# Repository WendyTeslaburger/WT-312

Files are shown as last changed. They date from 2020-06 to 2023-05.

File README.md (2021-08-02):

# WT-312, a MK-312 style driver on a stick!
## About:
This project aims to bring the hardware of e-stim/TENS to an easy-to-use module. Think: Sparkfun, Adafruit, DFRobot, etc.
I build this project with the main goal of interfacing to an ESP32 processor so many of the documentation or some design decissions will be made towards this processor. But you should be able to use your own favorite MCU.

This device tries to mimic the output stage of the well-known Erostec ET312 or better, the DIY reverse engineered MK-312. Hopefully by recreating this output stage, the same e-stim experience can be achieved as those devices.

## Current project status:
- ✅ Create V1.0 schematic+PCB
- ✅ V1.0 Testing and debugging 
- ✅ Commit V1.1 BOM patches
- ✅ Create V2.0 Schematic
- ✅ Route V2.0 PCB
- 🟧 Review process (ongoing)
- 🔲 Fix BOM with (available) alternative sources 
- 🔲 Order new batch of V2.0 PCBs

## Theory of operation:
### Output stage:
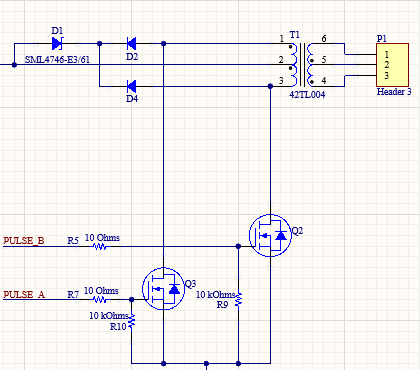
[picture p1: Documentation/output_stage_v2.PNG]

Just like the ET/MT312 this stick uses a 42TL004 audio transformer with the primary connected to the TENS output and the secondary connected to some circuitry to generate pulses.

These pulses are generated by the microcontroller, it can controll frequency (how many pulses per second) and the duration of each pulse.

A single "pulse"  consists of two steps:
1. Apply a voltage on A-signal. This will make one of both N-FETs conductive and current will start to flow through half the windings of the transformer.
2. Apply a voltage on the B-signal. This will make current flow through the other half of the transformer and reverse the polarity of the output TENS signal. Thus making this a bi-polar TENS driver.

To prevent the an excessive high drain-source voltage on the N-MOS drivers because of back-EMF generated by the transformer, two diodes will clamp this voltage to a zener diode on top of the centre-tap voltage.

### Level control:
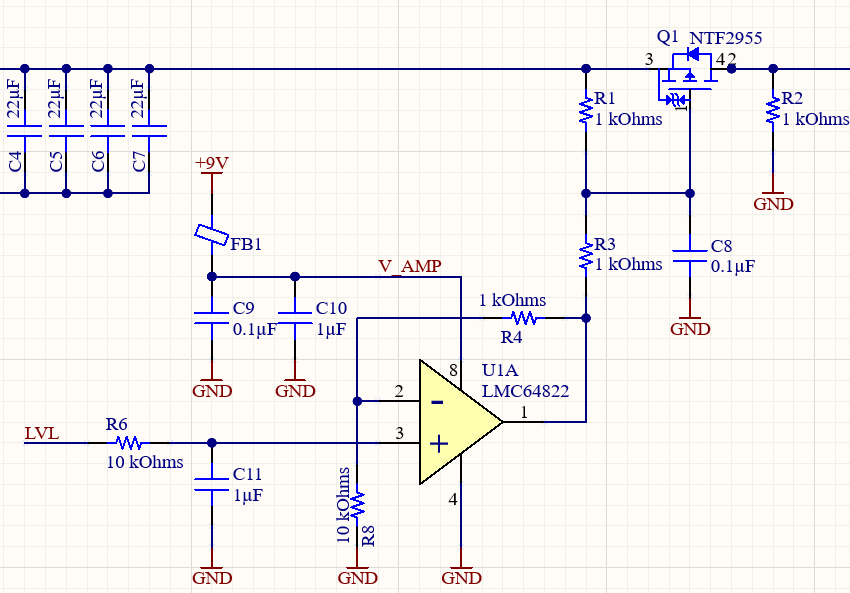
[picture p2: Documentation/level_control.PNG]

The intensity of a TENS stimulus is not only defined by the duration and frequency of the pulses, but also by the ouput power of that pulse. To control the output power of a pulse, we can limit how much current is flowing into the primary side of the transfomer.

By controlling the gate-voltage of a P-FET it is possible to control how much current that P-FET will allow to flow. An opamp is used to boost the I/o-voltage of the microcontroller to the 9V needed on the P-FET gate.

Important is to note that the LVL signal is inverted, a 0V means the P-FET is allowing maximal current and a 3.3V/5V will mean the P-FET is turned off.

### Current feedback:
Because not all P-FET are created 100% equally, it is important to first characterize the transfer curve between the LVL-signal and the current flowing through the transformer. This curve can be measured by the MCU on a embedded or external 
ADC on the *I_FB* pin of the WT-312 module.

To keep the voltage lost over the shunt resistor to a minimum, a small value shunt resistor is used and then amplified to the full-range of the ADC by an opamp.

## What is new in V2.0:
### 1. PWM
The DAC inside the ESP32 or ESP8266 is not great. Also, not every MCU has a built-in DAC to let alone 2, 3 or 4 DAC channels. However MCU's can generate pretty good resolution PWM signals and since the LVL signal does not require high bandwith, the V2.0 module has a R-C filter on the LVL signal so a PWM signal can be used instead of an analog DAC.
### 2. Improved clamping circuit
The clamping diodes in V1.0 ate into the power of the output. So they were removed in the patch. In V2.0 the clamping circuit is revised to let the voltage rise to a couple volts *above* the 9V input voltage. This should keep protecting the N-MOS but not impair the ouput power.
### 3. Bulk capacitance
Generating high-power pulses takes ... well ... power. These small 9V battery blocks have quite some internal resistance and are not able to generate the currents required for high-power TENS play. Not only batteries are bad a delivering pulses of several amps, also these ubiquitous chinese DCDC boost converter modules fail to deliver.

2 large electrolytic caps + a bunch of high value MLCC's will make sure that high current pulses to the primary can be delivered. The elco's can be mount sideways on the module to save some height.
### 4. LEDs
In this new design the REF pin is not used anymore. To keep compatibility between the V1.0 and V2.0 footprint the same number of pins was kept. This pin is now connected to a LED on the board. This LED is 100% optional and does not have to be stuffed, the footprint can be left empty.

## NodeMCU32s example (V1.0):
This is an example on how to connect the WT-312 module to the ESP32. This configuration will work with the provided example firmware.
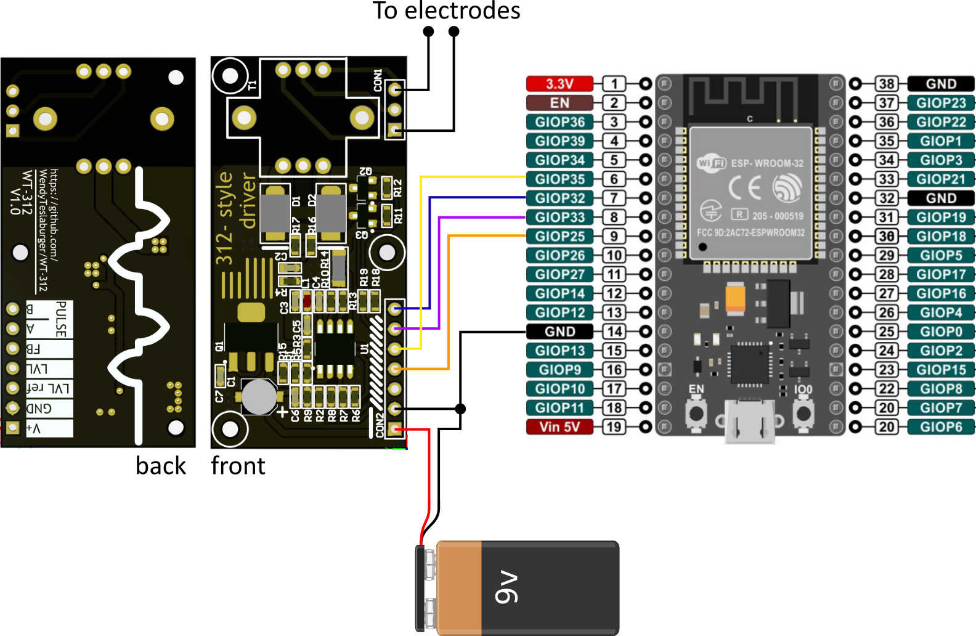
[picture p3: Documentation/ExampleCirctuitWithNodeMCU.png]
Connection example


## Licence:
All hardware design, software, images and documentation are licenced under the Creative Commons licence.

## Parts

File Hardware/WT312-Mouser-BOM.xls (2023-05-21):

SHOPPING BASKET
This is not an invoice
23-Apr-23 08:17:36
 | Mouser No | Mfr. No | Manufacturer | Customer No | Description | RoHS | Lifecycle | Order Qty. | Price (EUR)
1 | 80-C0603C104M5RAUTO | C0603C104M5RACAUTO | KEMET |  | Multilayer Ceramic Capacitors MLCC - SMD/SMT 50V 0.1uF X7R 0603 20% AEC-Q200 | RoHS Compliant |  | 3 | € 0,037
2 | 80-C0603C105K3R | C0603C105K3RACTU | KEMET |  | Multilayer Ceramic Capacitors MLCC - SMD/SMT 25V 1uF X7R 0603 10% | RoHS Compliant |  | 2 | € 0,179
3 | 81-GRM32ER71E226ME5L | GRM32ER71E226ME15L | Murata |  | Multilayer Ceramic Capacitors MLCC - SMD/SMT 22UF 25V 20% 1210 | RoHS Compliant |  | 4 | € 0,415
4 | 710-860020374012 | 860020374012 | Wurth Elektronik |  | Aluminium Electrolytic Capacitors - Radial Leaded WCAP-ATG5 470uF 16V 20% Radial | RoHS Compliant |  | 2 | € 0,244
5 | 78-SML4746-E3 | SML4746-E3/61 | Vishay |  | Zener Diodes 18 Volt 1.0W 10% | RoHS Compliant By Exemption |  | 1 | € 0,37
6 | 512-SS14FP | SS14FP | onsemi |  | Schottky Diodes & Rectifiers 40V 1A Schottky B arrier Rectifier | RoHS Compliant By Exemption |  | 2 | € 0,346
7 | 710-156120VS75000 | 156120VS75000 | Wurth Elektronik |  | Standard LEDs - SMD WL-SMRW SMD RvMt Mon Wtrclr Rect 1206BtGn | RoHS Compliant |  | 2 | € 0,184
8 | 704-MFBM1V1608-101-R | MFBM1V1608-101-R | Eaton |  | Ferrite Beads Multi H Cur, Impedance 100Ohm 2.5A SMT | RoHS Compliant |  | 1 | € 0,022
9 | 241-PJW4P06A_R200001 | PJW4P06A_R2_00001 | Panjit |  | MOSFET 60V P-Channel Enhancement Mode MOSFET | RoHS Compliant | New Product | 1 | € 0,348
10 | 621-DMN2041L-7 | DMN2041L-7 | Diodes Incorporated |  | MOSFET MOSFET,N-CHANNEL | RoHS Compliant |  | 2 | € 0,285
11 | 603-RC0603FR-101KL | RC0603FR-101KL | YAGEO |  | Thick Film Resistors - SMD 1 kOhms 100-200mW 06 03 1% | RoHS Compliant By Exemption |  | 4 | € 0,016
12 | 603-RT0603FRE1010RL | RT0603FRE1010RL | YAGEO |  | Thin Film Resistors - SMD 10 ohm 1% 50 ppm Thin Film | RoHS Compliant By Exemption |  | 2 | € 0,058
13 | 603-RC0603DR-0710KL | RC0603DR-0710KL | YAGEO |  | Thick Film Resistors - SMD 10 kOhms 100 mW 0603 1% | RoHS Compliant By Exemption |  | 5 | € 0,06
14 | 603-AC0603FR-10100KL | AC0603FR-10100KL | YAGEO |  | Thick Film Resistors - SMD 100 kOhms 100mW 0603 1% AEC-Q200 | RoHS Compliant By Exemption |  | 1 | € 0,028
15 | 603-RC0603FR-07560RP | RC0603FR-07560RP | YAGEO |  | Thick Film Resistors - SMD 560Ohms 1/10W 0603 1% | RoHS Compliant By Exemption |  | 2 | € 0,039
16 | 603-PE1206FRM7W0R1L | PE1206FRM7W0R1L | YAGEO |  | Current Sense Resistors - SMD 100 mOhms 1 Watt 1 % 75 ppm/C AEC-Q200 | RoHS Compliant |  | 1 | € 0,229
17 | 42TL004-RC | 42TL004-RC | Xicon |  | Audio Transformers / Signal Transformers XFMR 200CT-8 |  |  | 1 | € 3,78
18 | 926-LMC6482IM | LMC6482IM | Texas Instruments |  | Operational Amplifiers - Op Amps CMOS Dual RRIO OP Amp | No | NRND | 1 | € 2,44
19 | 523-G800W305018EU | G800W305018EU | Amphenol |  | Headers & Wire Housings Board mount - Header Plug - Pin Header 2.54mm Pitch Vertical,1x3Pin,Gold Flash,NY6T,6.1mm*2.5mm*3.0mm | RoHS Compliant |  | 1 | € 0,039
20 | 855-M20-9990746 | M20-9990746 | Harwin |  | Headers & Wire Housings 07 SIL VERTICAL PIN HEADER TIN | RoHS Compliant |  | 1 | € 0,234

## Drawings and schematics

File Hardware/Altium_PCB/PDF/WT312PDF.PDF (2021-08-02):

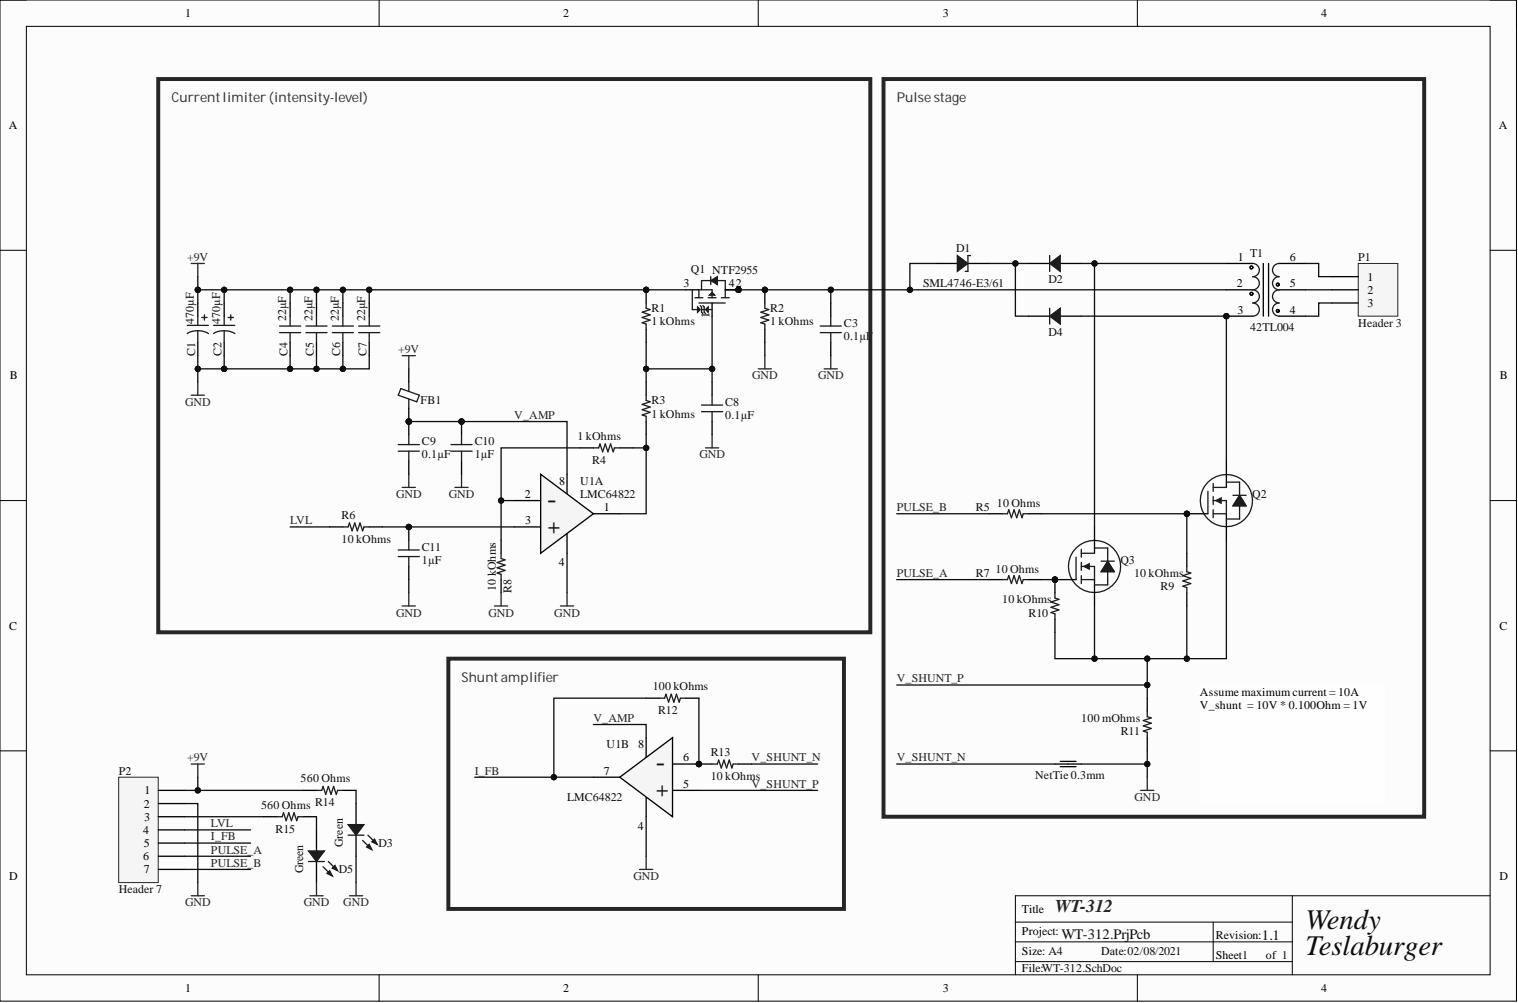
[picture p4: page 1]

Projec t : WT-3 1 2.P rj Pc b | Rev i s i o n : 1 . 1
Size : A 4 Dat e : 0 2 / 0 8 / 2 0 2 1 | Shee t 1 o f 1

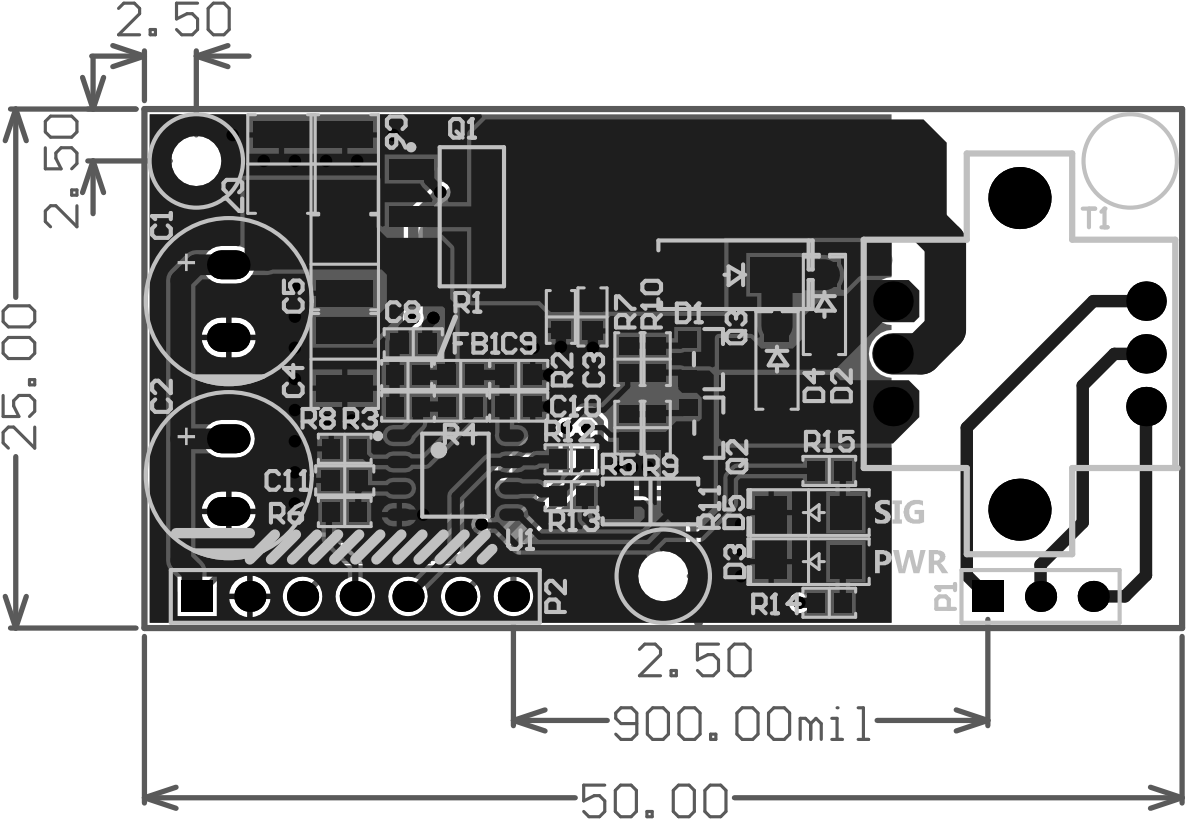
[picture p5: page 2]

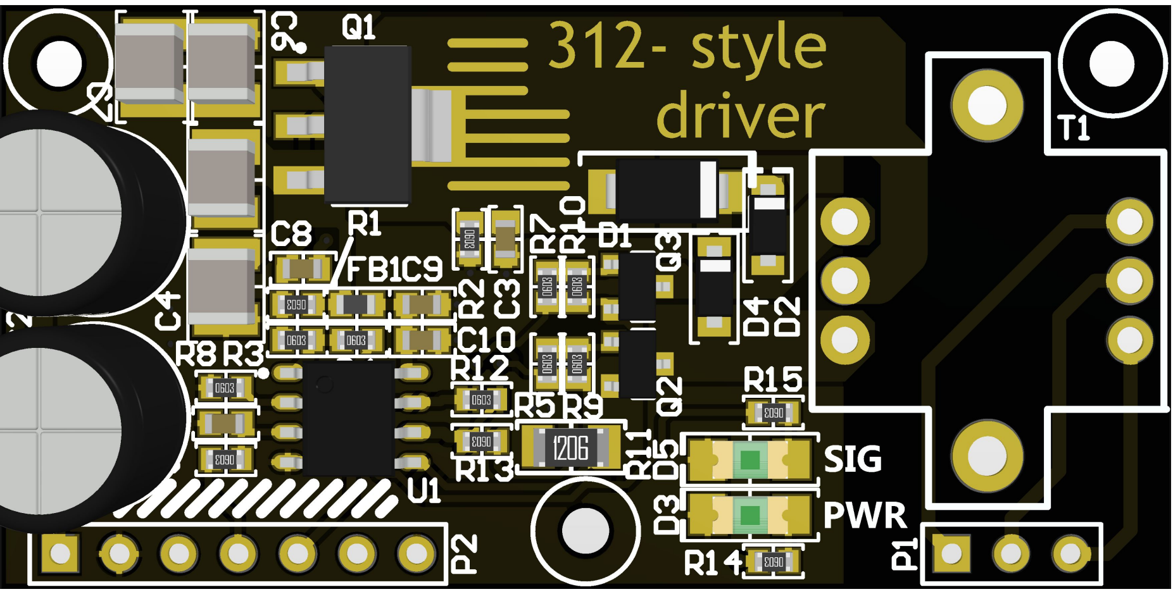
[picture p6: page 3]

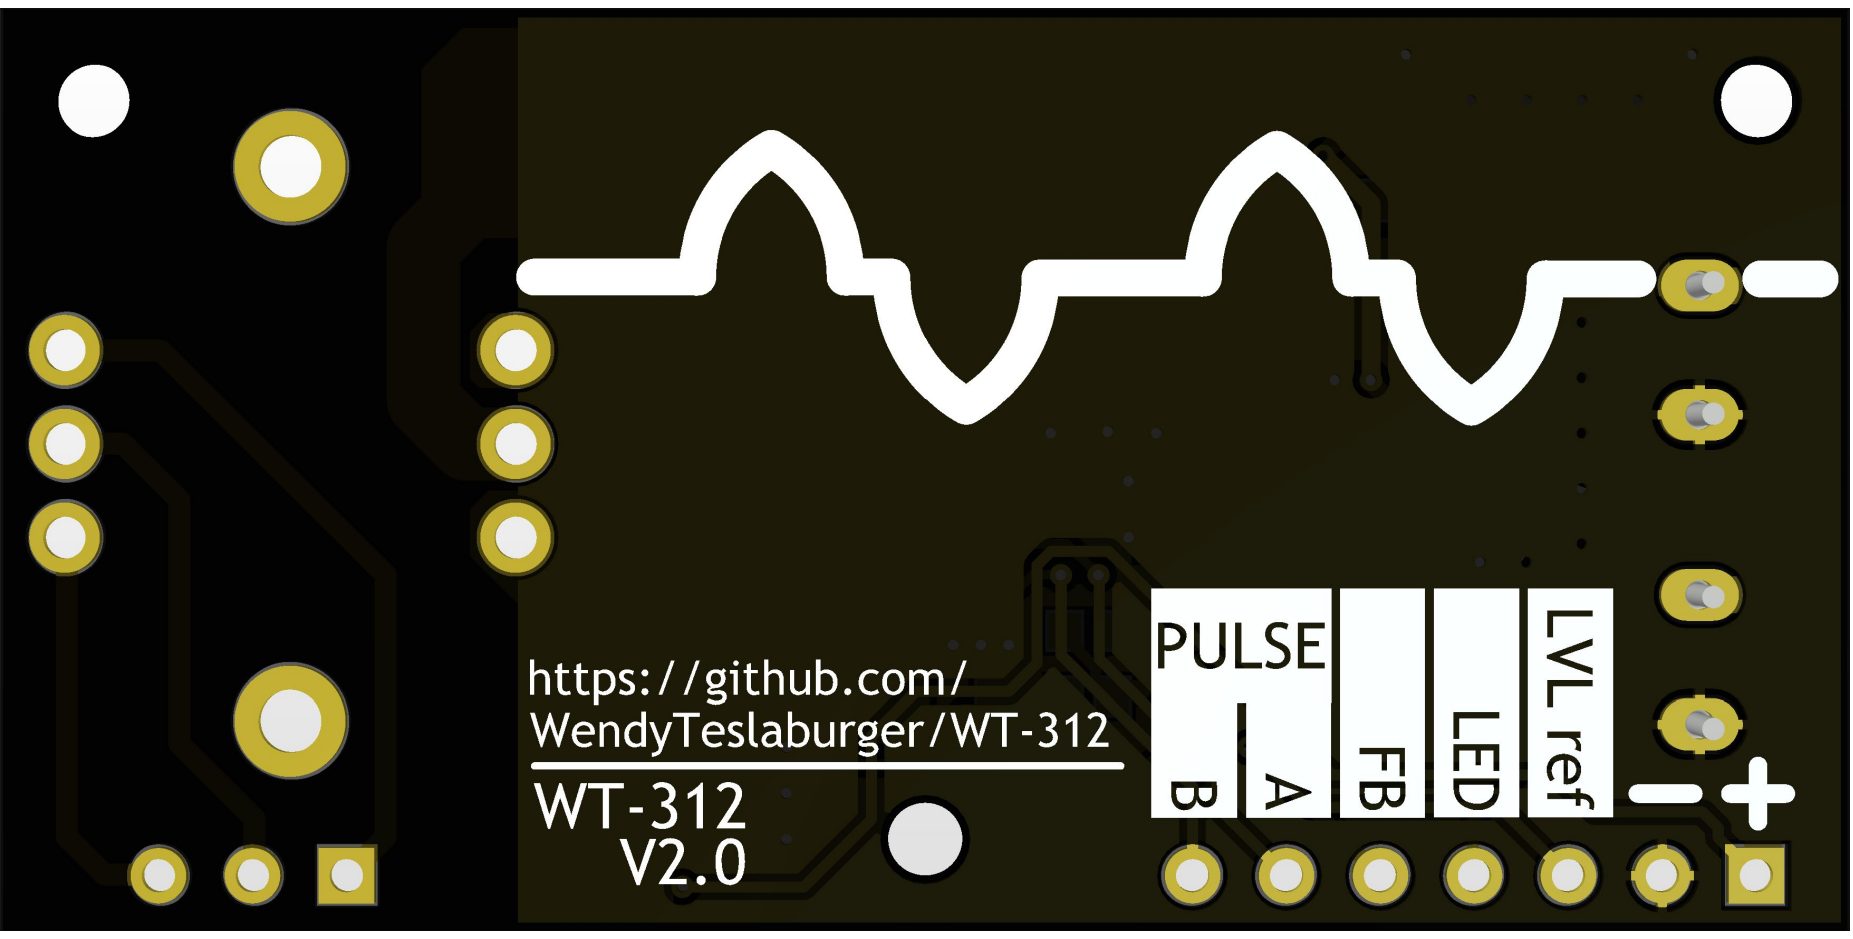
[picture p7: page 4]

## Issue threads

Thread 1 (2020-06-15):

T1 footprint optimisation

WendyTeslaburger, 2020-06-15:
The plated holes for the 42TL004 transformer are a bit on the tight side. Some force is required to push the mounting pins for the transformer, ruining the plating.
For extra mechanical support it would be good to also add exposed copper on top. So it is possible to solder the folded sheet metal to the PCB.
The issue does not affect performance, it only affects assembly.
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

Closed 2021-05-16.

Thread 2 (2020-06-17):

Feature request: Add PWM support

WendyTeslaburger, 2020-06-17:
Add support for low-pass filter on LVL, so the intensity can be set with PWM eliminating the need for a DAC.

WendyTeslaburger, 2021-07-19:
Implemented in the schematic: 2eabda08ca62eb708f5d9e8560ee80179203a66d

Closed 2021-07-19.

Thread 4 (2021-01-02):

Add bulk capacitance

WendyTeslaburger, 2021-01-02:
The bulk capacitance of 10uF is a few decades to low!
Something in the range of 1000uF - 2000uF should be sufficient.
When using alu-polymer caps, use a few in series to spread the ESR to a lower value.

WendyTeslaburger, 2021-07-19:
Implemented in schematic: 2eabda08ca62eb708f5d9e8560ee80179203a66d

Closed 2021-07-19.

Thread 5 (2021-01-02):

Current sense resistor on high side

WendyTeslaburger, 2021-01-02:
For increased output performance the, the shunt resistor can be decreased from 500mOhm to 100mOhm or even smaller.

WendyTeslaburger, 2021-07-19:
Implemented in schematic: 2eabda08ca62eb708f5d9e8560ee80179203a66d

Closed 2021-07-19.

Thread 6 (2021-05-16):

Schematic mismatch

maju101, 2021-05-16:
I seems that the pdf schematic and the PCB do not match. The schematic show 2 opamps (U1A and U1B), however the PCB only has room for 1.

I would greatly appreciate it if you could update the pdf schematic (and perhaps include a partslist). If you could do this update I will try to build it and add a partslist via Pull Request if I get it to work.

Thanks

WendyTeslaburger, 2021-05-16:
Hello, Thank you for your interest in my project!

U1A and U1B are both the same opamp. The LMC6482 is a dual opamp ([datasheet](https://www.ti.com/lit/ds/symlink/lmc6482.pdf?ts=1621152332898))
Splitting a component into multiple schematic subparts is a very common design technique.

However, after experimenting a bit with this module there are some slight variations I changed some component values for better performance. I should update these values into a new schematic PDF.

Best regards,
WT

maju101, 2021-05-16:
Ah ok cool.
Can I ask a couple more questions?

- The L1 coil is marked as z60. I'm assuming that's an impedance? If so, how does this translate to a coil rating in Henry?
- What size SMD components are you using? (i.e. 1206, 0603 ...)

Thanks
Cj

(and as promised, once I have everything assembled I'll add the full partslist via pullrequest so others who might be interested in this project can just buy everything without bothering you ;) )

WendyTeslaburger, 2021-05-18:
L1 is actually a filter bead. I could change the refdes to something like "FB1" to avoid confusion.
Z60 means that it has a 60ohm impedance at 100MHz. The filter bead is used to filter out protentional noise to the opamp. The noise could for example originate from a DCDC circuit to generate the 9v.

It is good practice to have it there, but I think the risk is low that the circuit would behave erratic if you just put a 0 ohm resistor there, or short the terminal with a solder blob.

The component size for the SMD components is 0603. For me this is the smallest size that is still comfortable to hand-solder.

jijzult, 2021-09-24:
I'd love a complete/matching BOM/schema too :) I'm following with great interests. I'll be trying to then make one with a LPR6235 coilcraft, so get a an ultrasmall size..

WendyTeslaburger, 2021-09-24:
I will try to get a BOM .csv file on the repo this weekend. Sorry for all the delays, I wish I had more time to work on this project.
Meanwhile some other kind strangers are testing out the design for me.

Regarding the LPR6235: I have doubts if this will work.
The LPR6235 is a tiny inductor and does not have a lot of material. This means that it will saturate quite fast.
The LPR6235-253LMR for example already saturates at 1.3A of primary current. This will not be sufficient for stronger e-stim output pulses.

maju101, 2021-09-24:
I was going to provide the bom as promised once I built it so I am sure
it's correct. But Mouser has absolutely massive delays. Currently expecting
my parts at the start of January...

On Fri, 24 Sep 2021, 17:04 WendyTeslaburger, ***@***.***>
wrote:

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

Closed 2023-05-21.

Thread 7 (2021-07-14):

small batch production run

McSwitchy, 2021-07-14:
Hi WendyTeslaburger - I am super impressed w/ your project and have been hoping someone would put together a small production run of the PCBs.

1. has anyone produced a batch of assembled PCBs or is planning to?

2. if not, I guess I would like to give it a shot. I've gotten pcb fab + assembly quotes from 1) circuithub.com and 2) pcbway.com in the past. However:

circuithub requires CAD files and not just gerbers - would you be willing to add those to this repo?
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

PCBway can work from gerber files, but needs a **centroid** file for each component for their pick-n-place process. See their requirements here: https://www.pcbway.com/helpcenter/pcb_assembly_ordering/

**first of all, is it ok w/ you for me to do a production run of this project? I would probably make 10-20 depending on price breaks and sell them at cost to anyone interested - alternatively I could just make a couple for personal use.** please let me know what you would prefer - I want to respect your wishes.

That said, assuming you support a small production run... Would you be open to:

1. creating the centroid file for PCBWay, or
2. providing the original atium design files so I can use circuithub;
2. and helping me pick good parts for the BOM
3. and providing advice (if any) on the optimal pcb and assembly options offered by pcbway (i.e. extra-thick copper layer for antenna / power / emf shielding etc)? See pcbway fab options in screenshot below

if not, I guess I would recreate the design in kicad or eagle and try out circuithub.

THanks! Other people interested in getting a board, chime in please so I can estimate interest.

McS

---

### PCBWAY manufacturing parameters

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

WendyTeslaburger, 2021-07-15:
Hey,
Thanks for your interest in the project! I will try to answer all your questions.

I have made a small batch of 10 PCBs at JLCPCB for testing and debugging the design. I hand-soldered them myself.
But as far as I'm aware, there has been no other production run.

I'm no copyright lawyer, but I tried to keep these project as open as possible so I included the Creative Commons Zero v1.0 licence. This should allow anyone to do whatever they want with the design. So I am 100% down with you running some production on these modules.

I use Altium Designer for my design work.
For this project I did not yet include the source documents because I was not sure if any personal information was inside .SchDoc or .PcbDoc metadata. For the WT-108 project I did some research and felt comfortable enough to commit the source documents. I will make a commit with the Altium source documents so you can use them (Circuithub) or even contribute to the project if you have an Altium licence.

Regarding the actual design itself: I had the chance to experiment with these boards and found some smal-ish issues. If any serious production run would be done, it would be best to make some changes to the design before making the modules.
Some are simple like substituting some component values with different values. But others would benefit from a small PCB redesign.

If you like, I could make these changes over the weekend and make a commit. Then we can have a look together at manufacturing options.

Best regards,
WT

McSwitchy, 2021-07-15:
Hi,

Most excellent! When you get the time to make the minor tweaks and then commit the updated atium files etc to the repo, I'll dig in and start trying to source parts and setting up a BOM. I'll try to do some of the heavy lifting there and also by soliciting a set of RFQs from the fab places. Then we can refine the BOM, order quantity, etc.

I'm glad I reached out, I've been meaning too for a year now :)

rexorient, 2021-07-22:
I would be interested in buying some assembled boards.

WendyTeslaburger, 2021-07-23:
Hello,
Sorry for the delay.
I have already made the changes to the schematic and committed the schematic in PDF together with the source .SchDoc file.
Next up I will change the routing a bit on the module PCB and commit that together with the Gerbers.

Regarding the BOM: I think the schematic is now as good as it gets with all the open issues fixed.
I will export a BOM list from Altium still today, then we can have a look if all components are available or if they need to be swapped for a different supplier (the component marking is crazy right now!)

Best regards,
WT

Deor, 2021-07-28:
Hi All,
I've just found this project and its just what i was looking for!
As I had also just put in an order with JLCPCB for some MK-312BT boards i decided to add this to the order too.
I know its still WIP, but for another £1.44 i thought why not!
If nothing else it will be good SMT soldering practice :)

KnkstrKex, 2021-08-05:
I'm also interesting in buying some (e.g. 5) completed boards.

h2omatt, 2022-09-11:
Did anyone make a few of these I am interested in buying a few to test with

EmiliaThorsen, 2024-06-08:
Any possibility for centroid files to be generated and added to the repo for production at jlcpcb/pcbway? I do not have altium so i can't generate the files myself, attempting to import the save files into kicad seems to have gotten the placements correctly, but i do not fully trust that it did everything correctly.

Otherwise a full conversion of the project to kicad would be amazing, but that is a lot to ask for so no need to, its only the centroid files for the pick and place i need to have it produced.

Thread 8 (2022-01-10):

Is there any software other besides the example?

Misaka13514, 2022-01-10:
Hi WendyTeslaburger! I am very interested in WT-312 because of its small size, low cost, etc.

I have completed the V2.0 of the hardware production.
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

When I tested the ESP32 software example, I found that neither V1 nor V2 software seemed to work properly on my device. It always enters the errorloop. (Sorry I don’t know how to view debugging information. I will try my best if you teach me.)

btw, is there any software other besides the example? Can the wireless function of esp32 be used to control pulse?

86lotus, 2023-03-31:
Hi .. did you ever get this working? I'm about to embark on a build and would love to know if yours worked out.

Do you have a BOM? Doesn't seem to be one in the project ...

Misaka13514, 2024-03-26:
@86lotus Sorry for the late reply. Yes I got this working recently. There is a BOM at https://github.com/WendyTeslaburger/WT-312/blob/master/Hardware/WT312-Mouser-BOM.xls

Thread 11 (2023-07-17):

Error Loop

weinca, 2023-07-17:
I built the circuit with some parts different from your BOM. I ran the code and it just stays in the error loop. I'm getting a voltage reading of 4095 for all the DACCode values in _characModule().
I was just wondering, during the _characModule(), should I connect something between the output or can I just leave it float?

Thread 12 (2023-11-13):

Is audio transformer primary/secondary correct?

thesnert, 2023-11-13:
Hi WendyTeslaburger

thank you very much for this project and the effort you've put into it. In the process of building my first board (v2) I've realized when installing the audio transformer that the schematics shows it with its primary (pin 1-3) oriented towards the amplifier circuitry and its secondary windings pointing towards output (datasheet: https://www.mouser.ch/datasheet/2/449/Yuetone_XC-600127-1212403.pdf).

If I compare the schematics with the mk312 (e.g. https://github.com/CrashOverride85/mk312-bt/blob/master/schematics/V1.4%20Main%20Boards/MK-312BT%20V1.4%2005-19-2019%20Board%20Layout.png), you'll see that they've installed their transformer with the secondary pointing towards the amp circuitry. Also @CrashOverride85 uses them in reverse in their zc95 built (https://github.com/CrashOverride85/zc95/blob/main/docs/Build.md; "Note that the transformers are used "backwards" - the side labelled primary goes to outputs.")

Thanks for clarifying!

Misaka13514, 2024-03-26:
I think you are right. The datasheet states that the number of primary turns is 400 and the number of secondary turns is 60. To achieve the boost effect, the side with more turns (i.e. the primary) needs to be connected to the output.

Having used this connection method in my own build (same as #1, pictured in #8), I think the schematic needs to be updated.

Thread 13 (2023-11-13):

Silkscreen v2 LED/LVL wrong?

thesnert, 2023-11-13:
Hi again,
I believe that the silkscreen in v2 on the back of the driver is misleading. The labeling should read:
 - PIN 3: LED (now LVL ref)
 - PIN 4: LVL (now LED)

Cheers,
theSnert

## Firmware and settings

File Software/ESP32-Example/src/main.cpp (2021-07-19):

#include <Arduino.h>
#include "pins.h"
#include <WT312.h>

/*
* Written by Wendy Teslaburger.
* USE AT OWN RISK!
* 
* This is some simple example code written to show how an ESP32 can interface with the WT-312 module.
* Eventually it would be nice to have everything nicely organised in a WT312-class, but that is something for later. 
*
*/

const int LED0 = 0;
uint8_t CH1_LED_VALUE = 0;

WT312 module1 = WT312(PIN_CH1_A, PIN_CH1_B, PIN_CH1_LVL, PIN_CH1_FB, PIN_CH1_LED);

void errorloop();

void setup() {
  pinMode(PIN_LED, OUTPUT);
  Serial.begin(115200);
  if(!module1.init()) errorloop();


  Serial.println("\n Starting loop\n=============");
}

void loop() {
  for(int intensity = 5; intensity <45; intensity+=5){
    module1.setIntensity(intensity);
    for(int pulseWidth = 100; pulseWidth < 300; pulseWidth+=25){
      module1.pulseTrain(pulseWidth, 100, 100);
      //delay(500);
    }
    for(int pulseWidth = 300; pulseWidth > 100; pulseWidth-=25){
      module1.pulseTrain(pulseWidth, 100, 100);
      //delay(500);
    }
    
  }
}

void errorloop(){
  while (true)  //ERROR!
    {
      digitalWrite(PIN_LED, HIGH);
      delay(100);
      digitalWrite(PIN_LED, LOW);
      delay(100);
    }
}

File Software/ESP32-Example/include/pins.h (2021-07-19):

const int PIN_CH1_LED = 4;
const int PIN_CH2_LED = 15;
const int CH1_LED = 1;
const int CH2_LED = 2;

const int PIN_LED = 2;

const int PIN_CH1_A = 14;
const int PIN_CH1_B = 12;
const int PIN_CH1_FB = 27;
const int PIN_CH1_LVL = 25;

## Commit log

2020-06-09 Add Gerber and PDF exports
2020-06-29 ESP32 firmware example.
2020-06-29 Update main.cpp
    Intensity is a value between 0 and 100.
    The code that tested the intensity levels still used the old 0-255 range. This is fixed.
    [main.cpp]
2021-07-19 HW-version 1.1 (WIP!!!)
    Schematic edited to fix a couple of issues.
    [WT-312.PrjPcb, WT-312.SchDoc]
2021-08-02 Routing of V2 version
    Routed the V2 version.
    The unused LVL pin changed to LED pin: So it can be used to drive a led. This is 100% optional!
    [WT-312.GBL, WT-312.GBO, WT-312.GBP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]
2023-05-13 added mouser bom, updated calibration
    [WT312-Mouser-BOM.xls]
2023-05-14 calibration improvement
